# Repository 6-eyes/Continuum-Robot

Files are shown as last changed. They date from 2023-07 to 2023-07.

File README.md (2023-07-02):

# Continuum-Robot
Head to Documentation [HERE](https://github.com/xD-prateek/Continuum-Robot/blob/main/Continuum%20Robotics.pdf).
___
| Component | Name |
| -- | -- |
|Motor Driver | TB6612FNG|  
|Motors | N20-3V micro|  
|Micro Controller | STM8S103F3P6|  

#### Constants
Threshold Voltage to move motor = 0.6V  
Backbone Dia = 3mm  
Tendon Dia = 0.45mm
___

### Objectives:
1. ~CAD model development and updation~
2.  ~Mathematical Model and analysis~
3. ~Testing Motor and Motor Drivers~
4. ~3D Printing Model and arranging~
5. Getting control over motors
6. Testing motors with a segment
7. Determining accuracy
8. Determining dynamics

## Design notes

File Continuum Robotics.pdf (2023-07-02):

# Continuum Robotics

This project consisted of design and control of a novel | lexible cable driven robot. The
basic design of the robot consists of three motors with 3D printed pulleys attached at its
head being used to move the tendons attached to it. The three motors are controlled by two
drivers with one being used to control two motors and the second driver being used to
control the third motor. A controller is used to vary the rpm as per the input given. The
de | lection of the tendons is to be measured using an IMU sensor. All these components are
housed in a 3D printed triangular segment.

## Modeling

In order to 3D print the model we designed the model on a CAD modeling software. The design is pretty basic, consisting of two triangular segments which house the motors, the drivers and the controllers and one Nitinol wire passing through the center of these two segments.

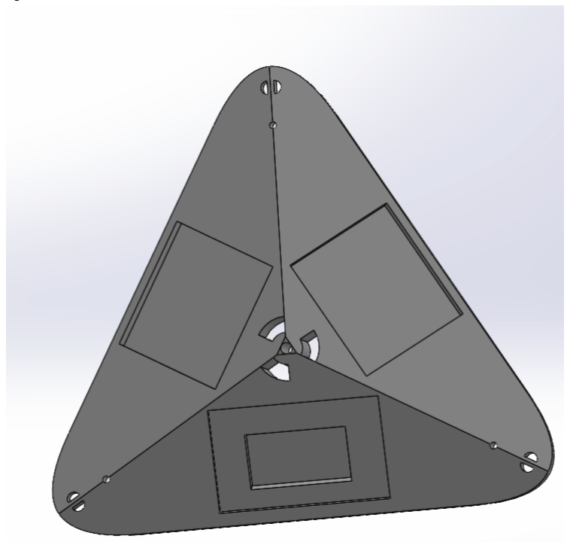
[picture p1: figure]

We chose a triangular segment since the model requires the usage of three motors and a triangular segment would ensure enough spacing for three motors to be housed with minimum usage of material. Three slots have been made on one side of the segment to keep the motors. The motors can be kept in place using glue or a double sided tape.

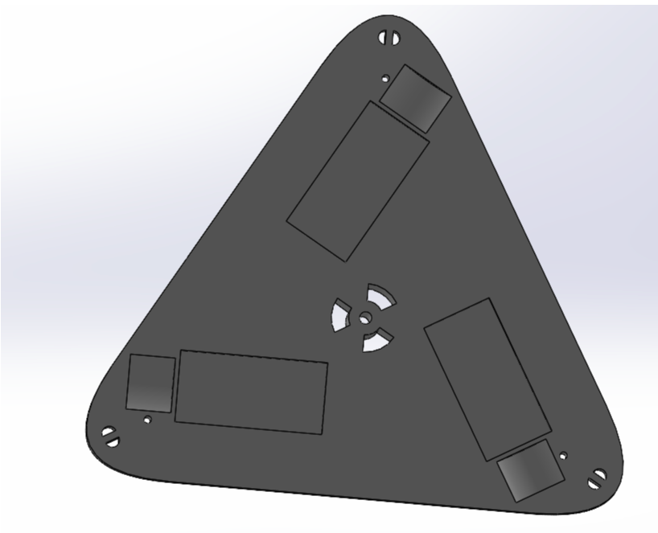
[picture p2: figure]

Two tiny holes are made in the region near the pulley attached to the motor. These holes

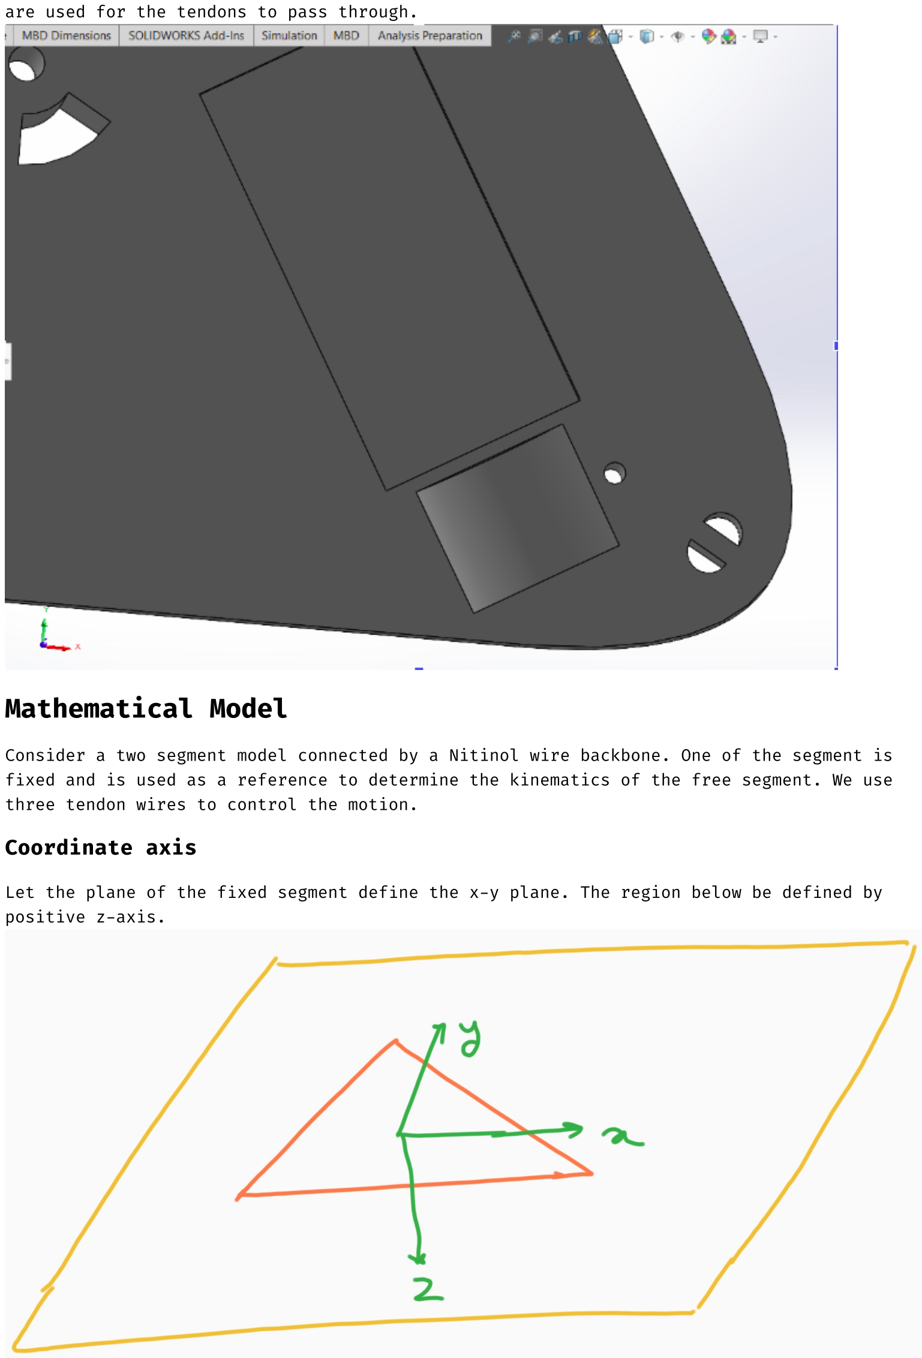
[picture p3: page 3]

are used for the tendons to pass through.

## Mathematical Model

Consider a two segment model connected by a Nitinol wire backbone. One of the segment is fxed and is used as a reference to determine the kinematics of the free segment. We use three tendon wires to control the motion.

### Coordinate axis

Let the plane of the fxed segment defne the xy plane. The region below be defned by positive zaxis.

### Terminologies

l ≡ the length of backbone between the two segments
θ ≡ the angle made by the two corresponding planes of the segments. Also the angle made by the free plane.
ϕ ≡ The angle made by the free segment with the xaxis.
a ≡ distance of tendon from center.
di ≡ d1, d2, d3, being the respective tendon lengths.

### Assumptions

1. Consider that each segment(of height 11.82 mm) is represented by a plane.
2. The backbone does not rotate i.e. the respective position of tendons remain same. There is no twisting.

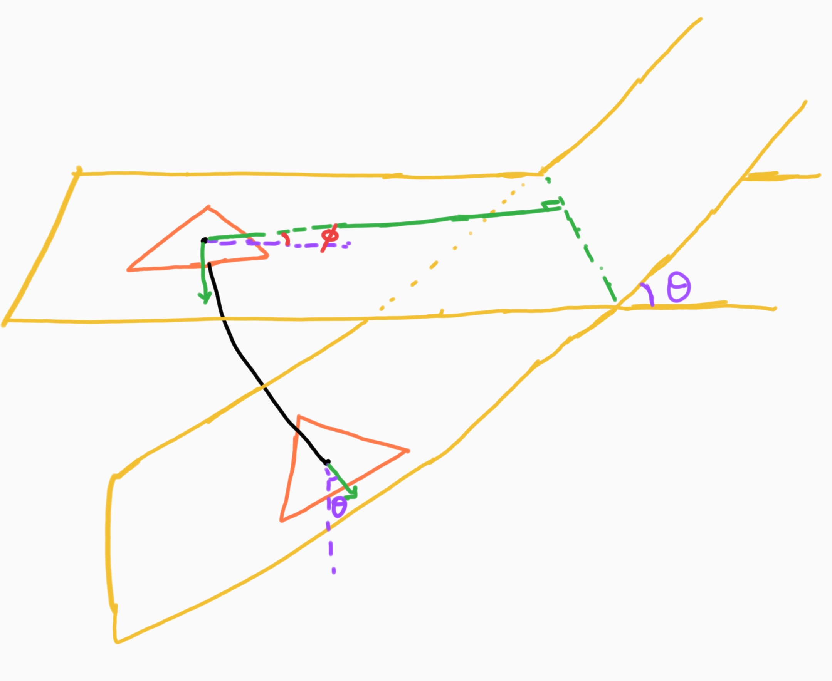
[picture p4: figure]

### Mathematical Derivation

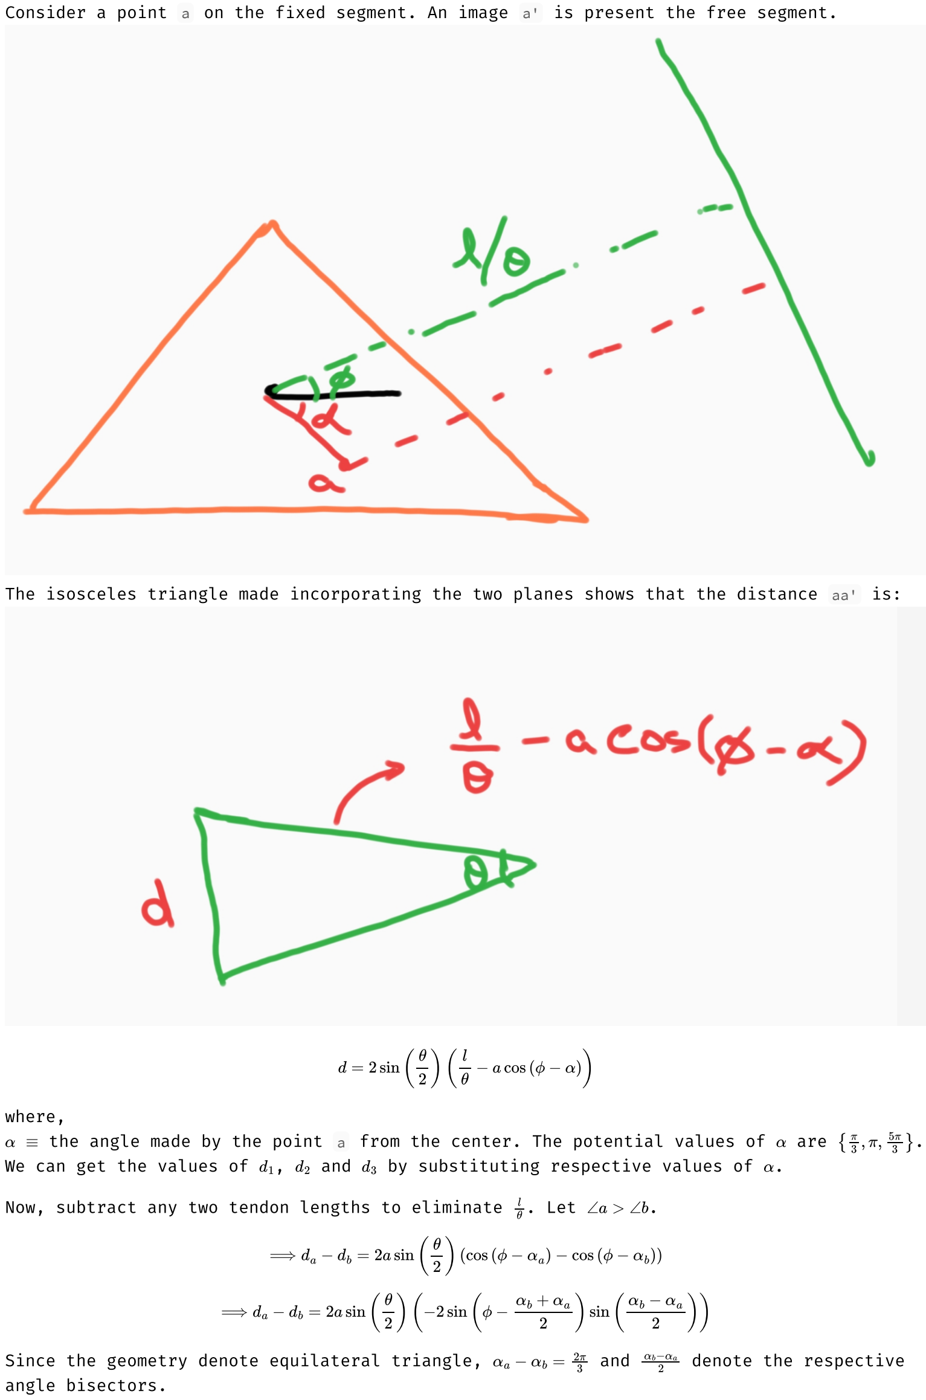
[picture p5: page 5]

Consider a point a on the fxed segment. An image a' is present the free segment.

The isosceles triangle made incorporating the two planes shows that the distance aa' is:

d = 2 sin (
θ

2

) (
l
θ

− a cos(ϕ − α))

where,
α ≡ the angle made by the point a from the center. The potential values of α are {
π
3

, π,

5π

3 }.
We can get the values of d1, d2 | and d3 | by substituting respective values of α.

Now, subtract any two tendon lengths to eliminate
| | l

θ . Let ∠a > ∠b.

⟹ da − db = 2a sin (
θ

2

) (cos(ϕ − αa) − cos(ϕ − αb))

⟹ da − db = 2a sin (
θ

2

) (−2 sin (ϕ −
αb + αa

2

# ) sin (

αb − αa

2

))

Since the geometry denote equilateral triangle, αa − αb = 2π 3 and

αb⁻αa
2 denote the respective
angle bisectors.

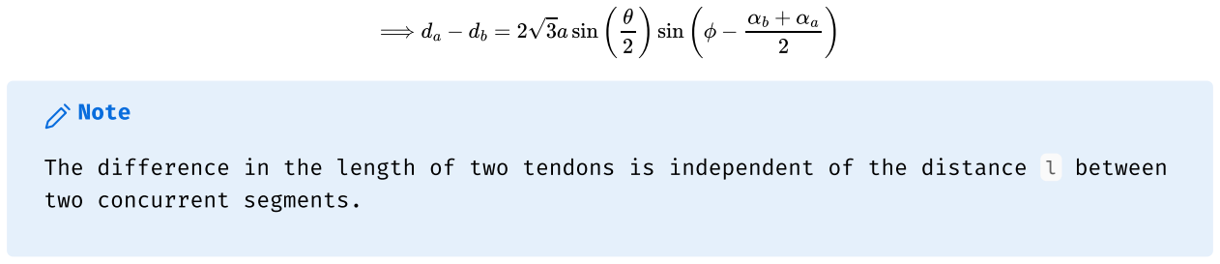
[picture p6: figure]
⟹ da − db = 2√3a sin (; ) sin (ϕ −; Note; two concurrent segments.

We now get three equations as follows:

a = 2, b = 1,

α2+α1
2 | =

π
3

⟹ d2 − d1 = 2√3a sin (
θ

2

) sin (ϕ −
π

3

)

a = 3, b = 2,

α3+α2
2

= π

⟹ d3 − d2 = 2√3a sin (
θ

2

) sin (ϕ − π)

a = 1, b = 3,

α1+α3

2

=

5π
3

⟹ d1 − d3 = 2√3a sin (
θ

2

) sin (ϕ −
5π

3

)

The above three equations can be used to determine the value of ϕ and θ as functions of d1,
d2 and d3.
Let any two equations be represented as,
| Δda = b sin (ϕ − βa)
| Δdb = b sin (ϕ − βa)
where,
| b = 2√3a sin (
θ
2 )

Dividing,

⟹

Δda

Δdb

=

sin (ϕ − βa)

sin (ϕ − βb)

Solving for ϕ,

⟹ tan (ϕ) =

sin (βa) −

Δda
Δdb

sin (βb)

cos(βa) −

Δda
Δdb

cos(βb)

Substituting any two values for Δd, we get,

⟹ tan (ϕ) =

√3 (d2 − d3)
(d1 − d2) + (d1 − d3)

Substituting value of ϕ in any equation,

⟹ b =

2
√3

√d
2
1 + d

2
2 + d

2
3 − d1d2 − d2d3 − d1d3

∴

⟹ sin (
θ

2

) =
1

3a

√d
2
1 + d

2
2 + d

2
3 − d1d2 − d2d3 − d1d3

### Conclusion

ϕ and θ can be written as the function of d1, d2 | and d3 | as,

ϕ = arctan (
√3 (d2 − d3)
(d1 − d2) + (d1 − d3)

)

The difference in the length of two tendons is independent of the distance l between

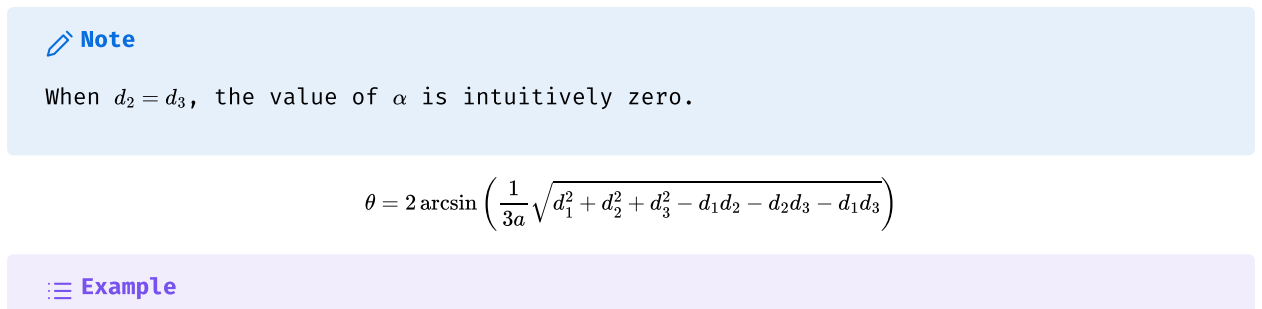
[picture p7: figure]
θ = 2 arcsin (; Note; Example

When d2 = d3, the value of α is intuitively zero.

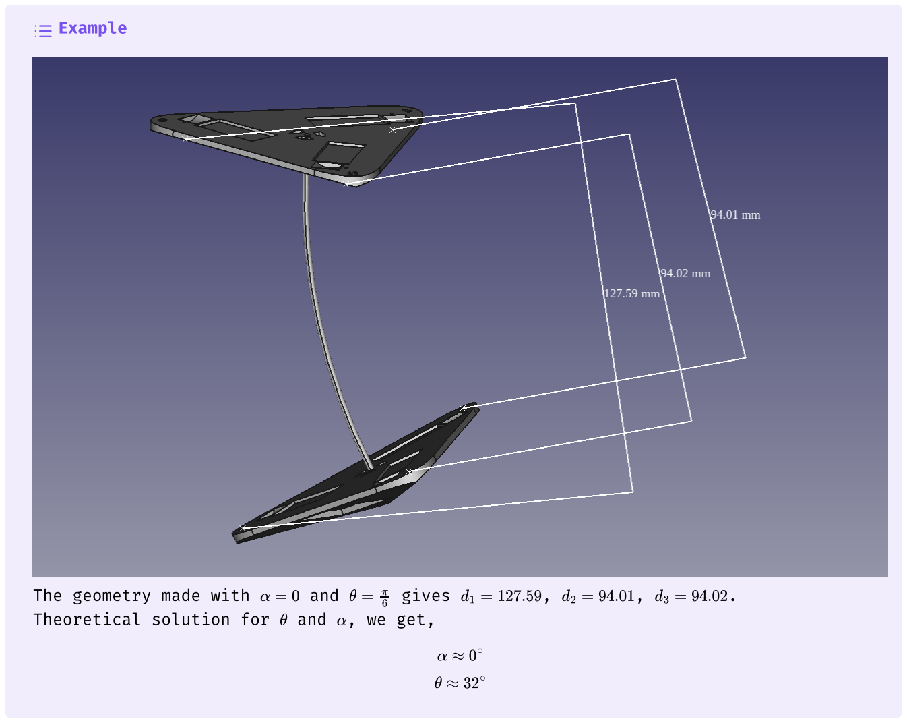
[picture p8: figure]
The geometry made with α = 0 and θ = π

6 gives d1 = 127.59, d2 = 94.01, d3 = 94.02.
Theoretical solution for θ and α, we get,

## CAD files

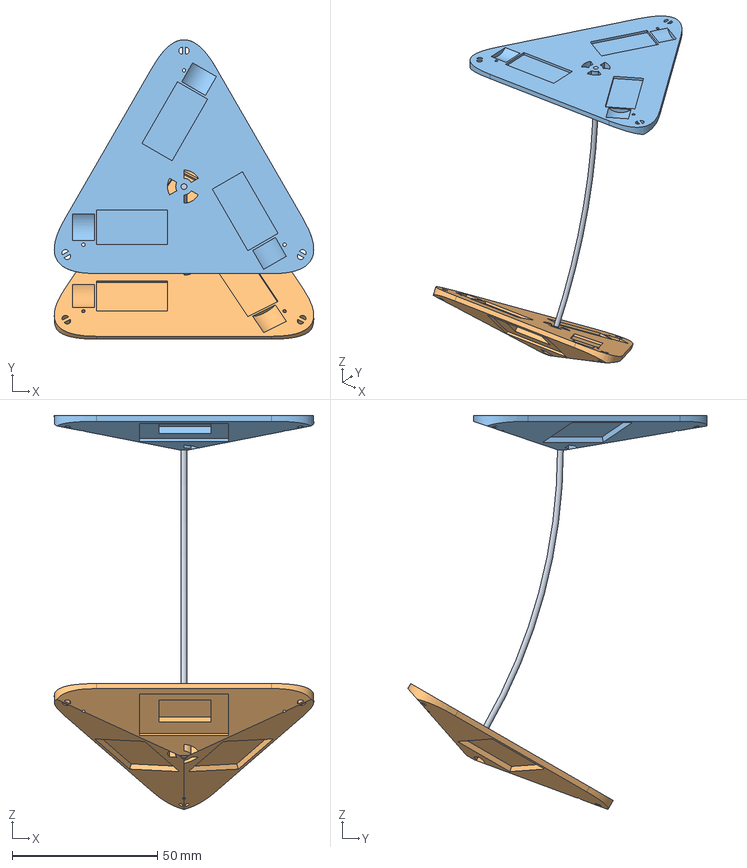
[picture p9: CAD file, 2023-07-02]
Model/Assembly.FCStd
89.4 x 103.1 x 135.7 mm
segment1_Nitinol wire_001
segment1_Body_002
segment1_Body_001

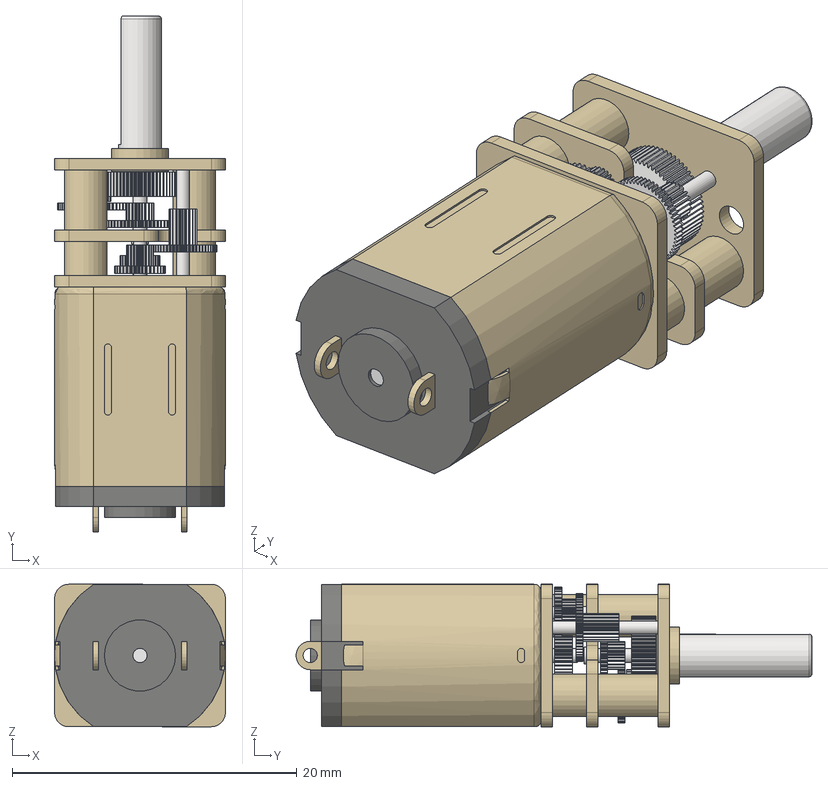
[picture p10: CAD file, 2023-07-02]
Model/N20_micromotor.FCStd
12.0 x 36.2 x 10.0 mm
Base
Rotor
Apoio Contato
Contato
Suporte Contato
Im\X\E3s
Terminais
Terminais001
Escovas
Chapa Intermedi\X\E1ria
Chapa Superior
Eixo Maior - Engrenagem
Eixo M\X\E9dio - Engrenagem
Parafuso
Parafuso001
Suporte Bobinas
Eixo Menor - Engrenagem
Engrenagem reta12
Engrenagem reta22
Engrenagem reta11
Engrenagem reta21
Eixo - Encaixe D
Engrenagem reta15
Engrenagem reta25
Engrenagem reta17
Engrenagem reta27
Engrenagem reta18
Engrenagem reta28
Carca\X\E7a

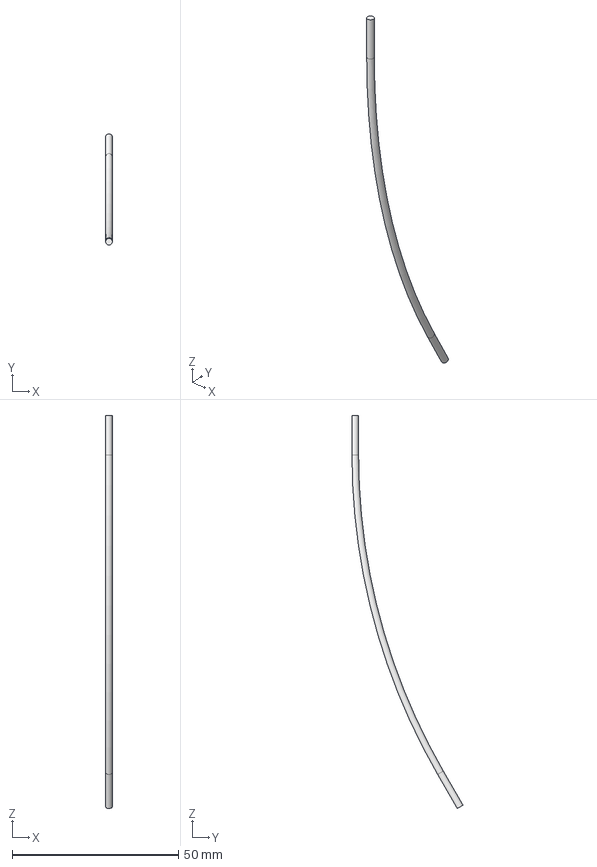
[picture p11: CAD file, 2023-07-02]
Model/segment1.FCStd
2.01 x 33.4 x 118.1 mm

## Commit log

2023-04-05 Add files via upload
    Updated Segment model
    [segment1.FCStd]
2023-07-02 Add files via upload
    Segment design + N20 Motor + Complete Assembly
    [Assembly.FCStd, N20_micromotor.FCStd, segment1.FCStd]
